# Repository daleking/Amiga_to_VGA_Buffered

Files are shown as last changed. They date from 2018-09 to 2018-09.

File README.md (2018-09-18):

# Amiga Buffered VGA Adaptor

This VGA buffered adaptor uses a SN74HCT08PWR to keep the size down (and stay true to the original Commodore design).  You will also need a DB23 female solder cup connector and a VGA PCB mount connector (and a capacitor).

This is a replacement for the original [390682-01](http://bboah.amiga-resistance.info/cgi-bin/showhardware_en.cgi?HARDID=733)

I don't know what the other chip in the [390682-03](http://bboah.amiga-resistance.info/download_photos/comm_vgaconv4.jpg) is, or what the diodes (protection?) are for either.  Apparently this version has a fix for video toasters, so assume that this repro will behave the same and not work with video toasters either.

The design is upside down so that there is minimal strain on the DB23 video connector.  The VGA cable lies close to flat on the table.  I didn't want the weight of the cable pulling down on the connector.

No warranty, although I have built one and tested on A4000, A2000 and A500.

This method is a lot easier than stripping wires and soldering the cups :)

If you are lazy, you can order PCBs from [dirtypcbs.com](http://dirtypcbs.com/store/designer/details/dalek/6137/amiga-to-vga-buffered-zip) and using that link I get a dollar woo!  If you are cheap just grab the gerber zip file and get them done wherever you like.

I suggest 1.2mm board thickness (1.6mm works but is a tight fit).

Dale

## Schematic
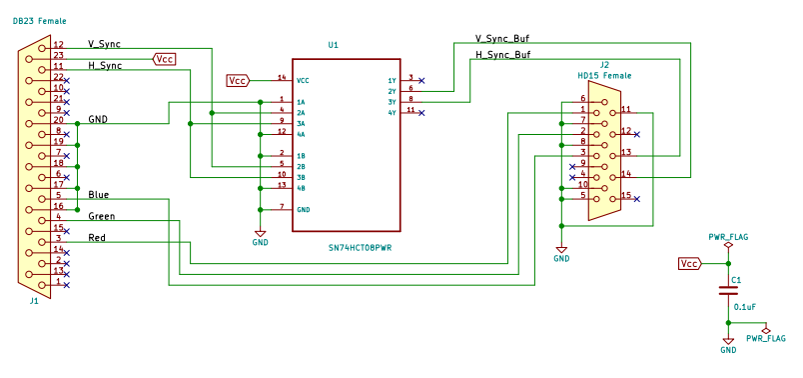
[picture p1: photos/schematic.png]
schematic


## Bottom
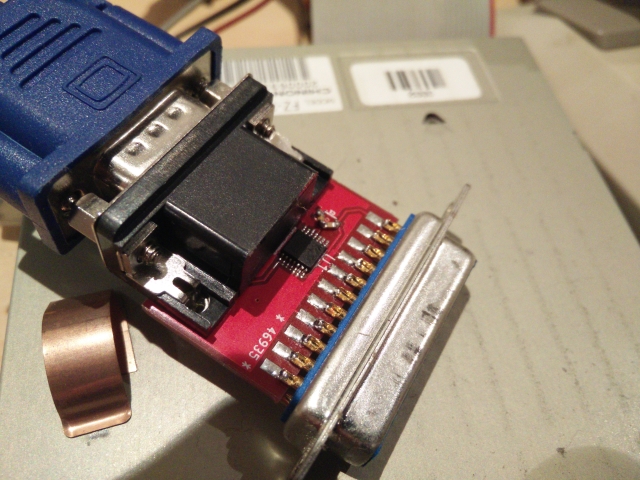
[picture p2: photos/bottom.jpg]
bottom


## Top
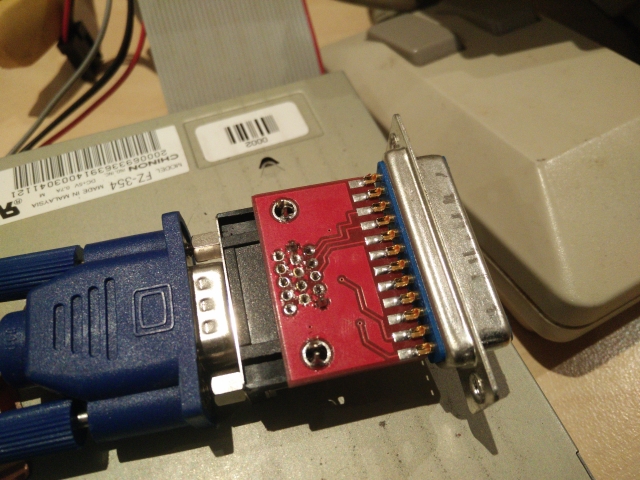
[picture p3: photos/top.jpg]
top


## Connected
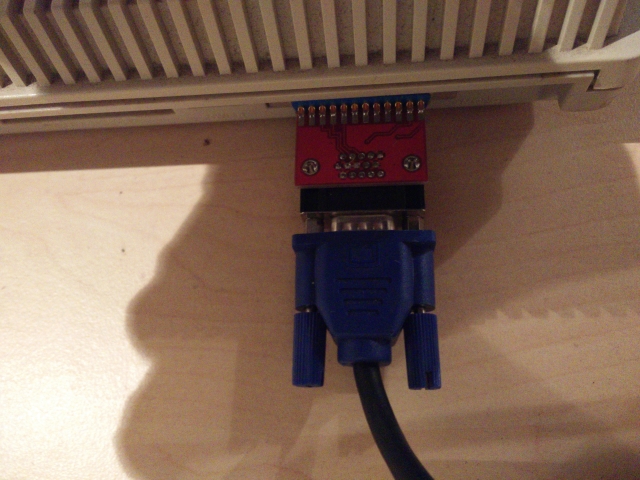
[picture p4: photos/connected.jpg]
connected


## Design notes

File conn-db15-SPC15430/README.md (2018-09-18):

DE15 connector
==============

  Footprint and 3D model for MULTICOMP SPC15430 DE-15 connector.

Component datasheet from Farnell website:
http://www.farnell.com/datasheets/480593.pdf

FROM: https://github.com/Agilack/contrib-kicad_parts

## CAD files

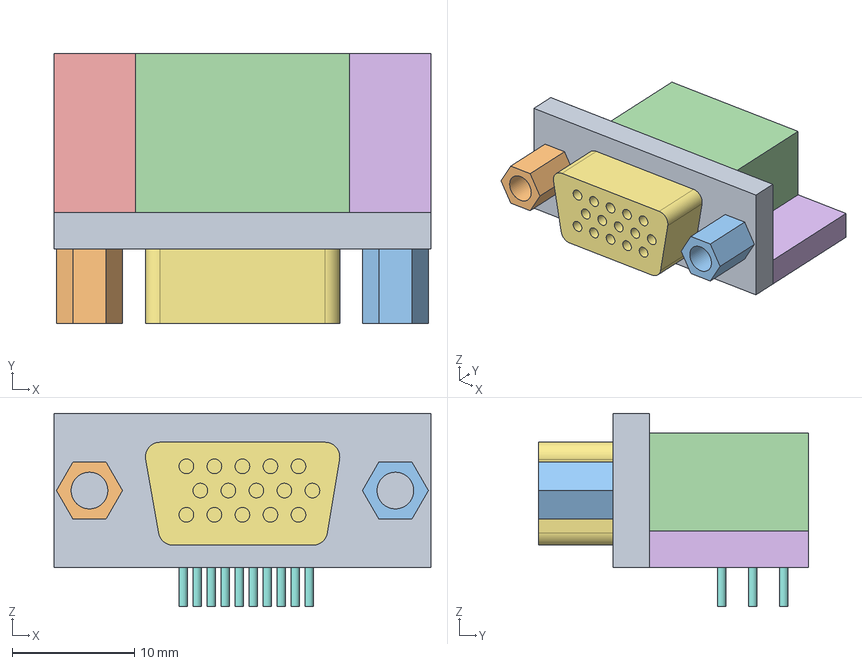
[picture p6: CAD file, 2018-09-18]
conn-db15-SPC15430/conn_SPC15430.fcstd
30.8 x 22.1 x 15.8 mm
Front
Fix2
Fix1
BoxRear
RearFix2
RearFix003
Pins

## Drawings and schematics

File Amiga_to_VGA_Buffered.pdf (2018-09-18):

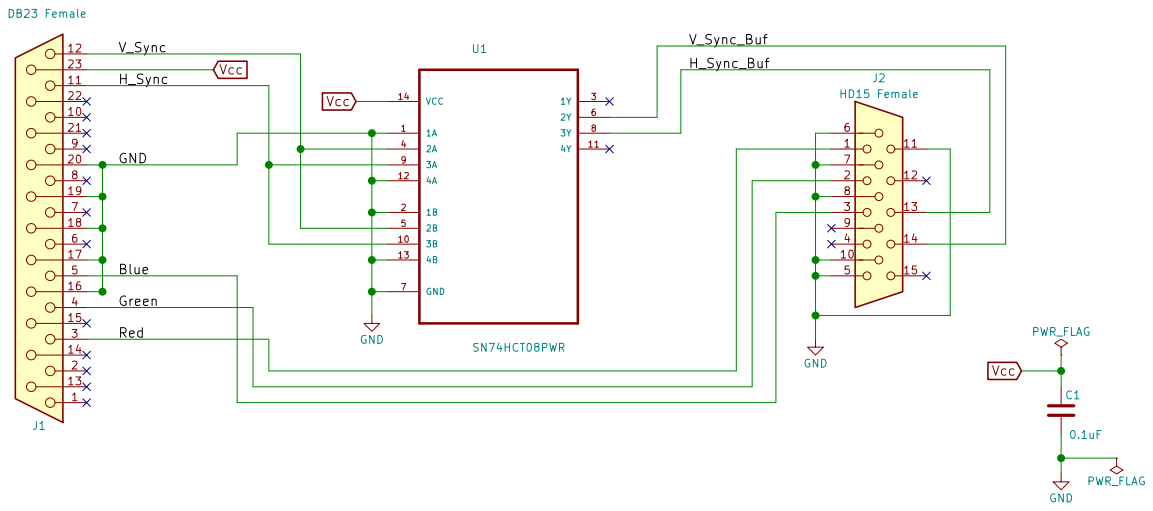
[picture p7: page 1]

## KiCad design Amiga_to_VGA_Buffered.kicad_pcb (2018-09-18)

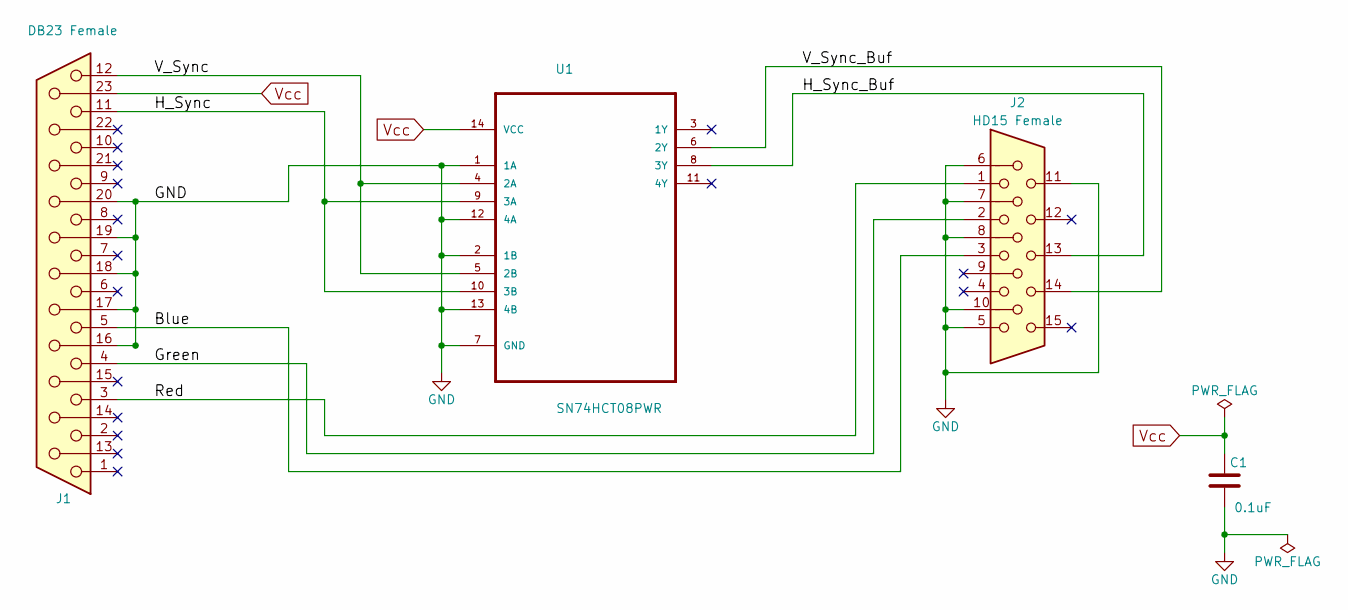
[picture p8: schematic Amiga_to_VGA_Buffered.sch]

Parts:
C1: 0.1uF; C_1206
J1: DB23 Female; conn-db23_Female_Solder_Cup
J2: HD15 Female; conn_SPC15430
U1: SN74HCT08PWR; SOP65P640X120-14N

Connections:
/Blue: J1.5, J2.3
/Green: J1.4, J2.2
/H_Sync: J1.11, U1.9 (3A), U1.10 (3B)
/H_Sync_Buf: J2.13, U1.8 (3Y)
/Red: J1.3, J2.1
/V_Sync: J1.12, U1.4 (2A), U1.5 (2B)
/V_Sync_Buf: J2.14, U1.6 (2Y)
GND: C1.2, J1.16, J1.17, J1.18, J1.19, J1.20, J2.5, J2.6, J2.7, J2.8, J2.10, J2.11, U1.1 (1A), U1.2 (1B), U1.7 (GND), U1.12 (4A), U1.13 (4B)
Vcc: C1.1, J1.23, U1.14 (VCC)

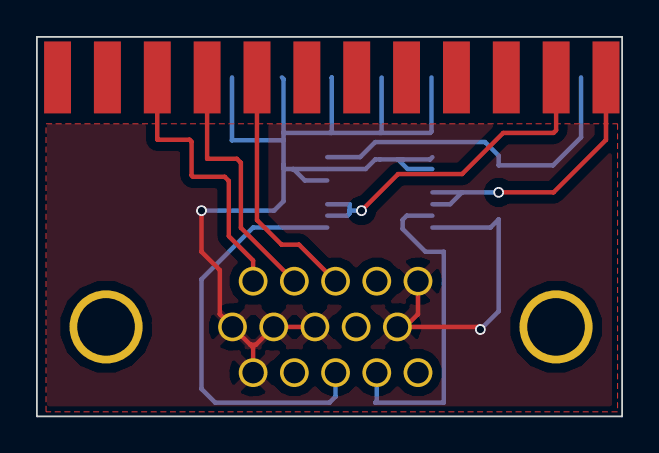
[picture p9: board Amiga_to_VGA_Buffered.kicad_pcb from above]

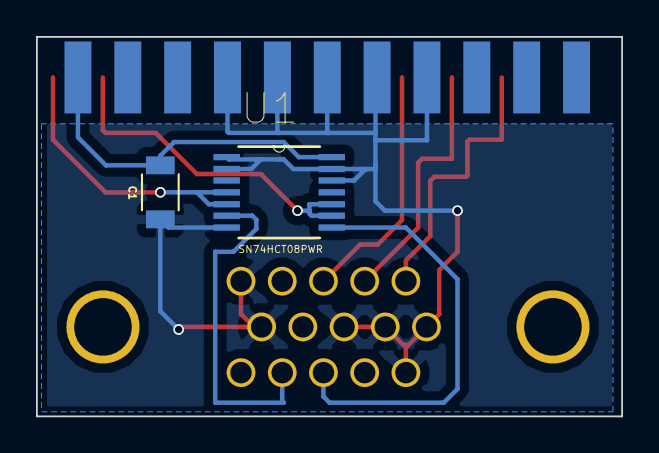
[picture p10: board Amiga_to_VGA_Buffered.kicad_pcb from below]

Board: 2 copper layers, 32.5 x 21.1 mm, 4 parts (3 on the bottom side), 9 nets.
